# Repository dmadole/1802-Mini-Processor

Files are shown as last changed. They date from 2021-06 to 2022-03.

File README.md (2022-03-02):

# 1802-Mini-Processor
This is the 1802 processor card for the [1802/Mini](https://github.com/dmadole/1802-Mini) system. It supports the following features:

* CDP1802, CDP1804 (A only), CDP1805, or CDP1806 processors
* 64K of memory in two 32K RAM, EPROM, or EEPROM devices
* Supports 62C64, 62C256, 27C64, 27C256, 28C64, 28C256
* Can temporarily map a ROM at $8000 to $0000 at reset
* Eight  indicator LEDS with selectable polarity for each
* TTL level port with Q and selectable EF pin for soft serial
* Transmit and receive polarity selectable on serial port
* Designed for 4 Mhz but can run 8Mhz with suitable processor
* Stable power-on reset circuit is jumper-selectable
* Convenient mini-USB connector for 5 volt power input
* Form factor allows stacking or backplane by connector choice
* Can run totally standalone or expanded with additional cards
* Configurable to be able to run most "Classic Elf" software
* Highly annoted silkscreen documents most settings and pins

Gerber files for the PCBs and PDF schematics can be found in [Releases](https://github.com/dmadole/1802-Mini-Processor/releases).

BOMS and any applicable errata or other notes can be found in [notes](https://github.com/dmadole/1802-Mini-Processor/tree/main/notes).

For availability of kits and bare PCBs please see http://madole.net/1802/mini/kits

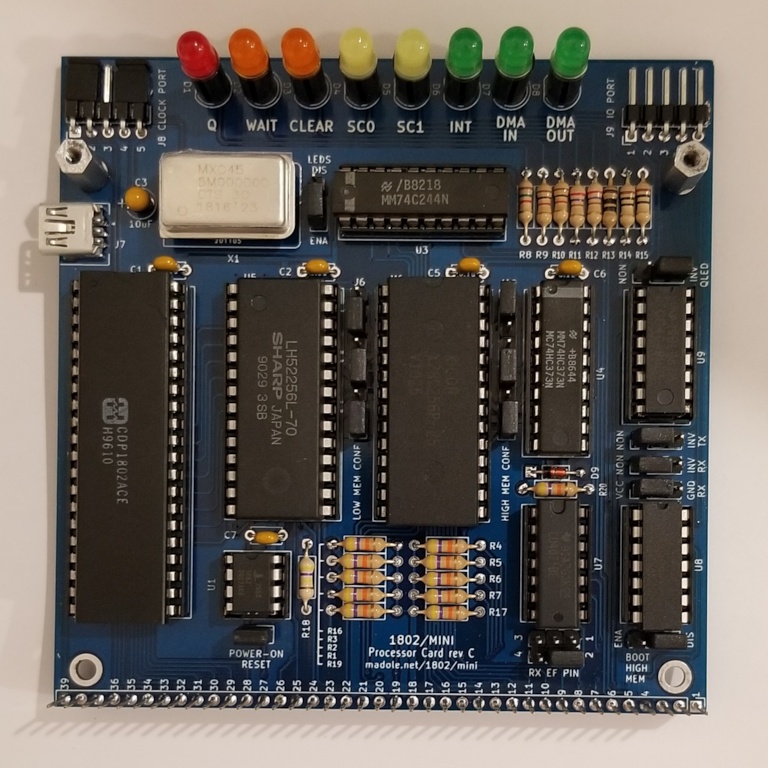
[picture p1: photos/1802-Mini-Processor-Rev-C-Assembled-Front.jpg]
1802/Mini Processor Front

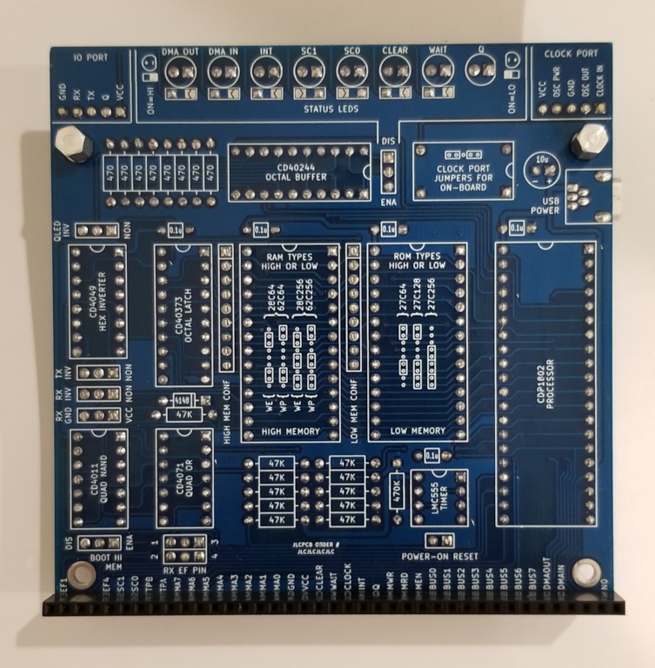
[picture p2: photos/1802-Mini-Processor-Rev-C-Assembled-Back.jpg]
1802/Mini Processor Back


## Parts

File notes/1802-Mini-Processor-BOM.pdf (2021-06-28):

Please refer to these notes as applicable for the parts list below:

*A

*B | Rev A and Rev B boards and schematics specified 47K ohms for all of R1-7 and R16-19. Recommended values are shown as below, use location reference for placement.
*C | The header pins for configuration jumpers are cut down from longer strips.
*D | The Samtec 39 pin connector, when ordering from Digikey, will always show zero stock because they are made-to-order. They will ship same or next day though.
*E | Virtually any of the many 555 timer clones can be subtituted, with CMOS parts preferred. The part numbers shown are not the only possible substitutes.

### PROCESSOR CARD

Qty | Description | Manufacturer Manufacturer # | Vendor | Vendor # | Price | Qty | Total

Integrated Circuits
1 | CDP1802 | U2 | Harris | CDP1802AEX | Rochester CDP1802AEX | 5.46 | 1.00 | 5.46
1 | 32K x 8 CMOS SRAM | U5 | Sharp | LM62256L-70 | Jameco | 82472 | 3.95 | 1.00 | 3.95
1 | 32K x 8 CMOS EEPROM | U6 | Atmel | 28C256-25 | Jameco | 74878 | 4.95 | 1.00 | 4.95
1 | CD40244 (or 74C244 or 74HC244) | U3 | TI | SN74HC244N | Digikey | 296-1582-5-ND | 0.61 | 1.00 | 0.61
1 | CD40373 (or 74C373 ot 74HC373) | U4 | TI | SN74HC373N | Digikey | 296-1591-5-ND | 0.66 | 1.00 | 0.66
1 | CD4049 | U9 | TI | CD4049UBE | Digikey | 296-2055-5-ND | 0.66 | 1.00 | 0.66
1 | CD4071 | U7 | TI | CD4071BE | Digikey | 296-2062-ND | 0.66 | 1.00 | 0.66
1 | CD4011 | U8 | TI | CD4011BE | Digikey | 296-2031-ND | 0.66 | 1.00 | 0.66
1 | LMC555 (or ICP7555) (*E) | U1 | Renesas | ICM7555IPAZ | Digikey | ICM7555IPAZ-ND | 0.87 | 1.00 | 0.87
1 | Oscillator module full size | X1 | Epson | MXO45-3C-4M000000 | Digikey | 110-MXO45-3C-4M000000-ND | 2.18 | 1.00 | 2.18

Discrete Components
1 | LED T1-3/4 Red (*A) | D1 | Valuepro | UT1871-81-M1-R | Jameco | 333973 | 0.12 | 1.00 | 0.12
2 | LED T1-3/4 Orange (*A) | D2-3 | Valuepro | LE3330 | Jameco | 107393 | 0.12 | 2.00 | 0.24
2 | LED T1-3/4 Yellow (*A) | D4-5 | Valuepro | LY3330 | Jameco | 34825 | 0.15 | 2.00 | 0.30
3 | LED T1-3/4 Green (*A) | D6-8 | Valuepro | LG3330 | Jameco | 34761 | 0.15 | 3.00 | 0.45
3 | Resistor 1/4 watt 10 (*A) | R13-15 | Stackpole | CF14JT10R0 | Digikey | CF14JT10R0CT-ND | 0.10 | 3.00 | 0.30
2 | Resistor 1/4 watt 270 (*A) | R11-12 | Stackpole | CF14JT270R | Digikey | CF14JT270RCT-ND | 0.10 | 2.00 | 0.20
2 | Resistor 1/4 watt 1K (*A) | R9,R10 | Stackpole | CF14JT1K00 | Digikey | CF14JT1K00CT-ND | 0.10 | 2.00 | 0.20
2 | Resistor 1/4 watt 1.5K (*A) | R8 | Stackpole | CF14JT1K50 | Digikey | CF14JT1K50CT-ND | 0.10 | 2.00 | 0.20
10 | Resistor 1/4 watt 4.7K (*B) | R1-7,16-17,19 | Stackpole | CF14JT4K70 | Digikey | CF14JT4K70CT-ND | 0.10 | 10.00 | 1.00
1 | Resistor 1/4 watt 47K (*B) | R20 | Stackpole | CF14JT47K0 | Digikey | CF14JT47K0CT-ND | 0.10 | 1.00 | 0.10
1 | Resistor 1/4 watt 470K | R18 | Stackpole | CF14JT470K | Digikey | CF14JT470KCT-ND | 0.10 | 1.00 | 0.10
1 | Diode 1N4148 | D9 | ON Semi | 1N4148 | Digikey | 1N4148FS-ND | 0.10 | 1.00 | 0.10
5 | Ceramic capacitor 0.1uF radial 0.2" | C1-2,5-7 | Valuepro | SR215C104KAA | Jameco | 544921 | 0.19 | 5.00 | 0.95
1 | Tantalum capacitor 10uF radial 0.1" | C3 | AVX | TAP106K010SCS | Digikey | 478-1838-ND * | 0.8 | 1.00 | 0.80

Interconnects
1 | Straight header 2 pins 0.1" (*C) | | Sullins | PREC040SAAN-RC | Digikey | S1012EC-40-ND | 0.51 | 0.05 | 0.03
8 | Straight header 3 pins 0.1" (*C) | | Sullins | PREC040SAAN-RC | Digikey | S1012EC-40-ND | 0.51 | 0.60 | 0.31
2 | Straight header 9 pins 0.1" (*C) | | Sullins | PREC040SAAN-RC | Digikey | S1012EC-40-ND | 0.51 | 0.45 | 0.23
2 | Right-angle header 5 pins 0.1" (*C) | | Sullins | PREC040SBAN-M71RC | Digikey | S1112EC-40-ND | 0.66 | 0.25 | 0.17
16 | Jumper shunts 0.1" | | Sullins | STC02SYAN | Digikey | S9000-ND | 0.10 | 16.00 | 1.60
1 | Socket 39 pin 0.1" long tail (*D) | | Samtec | SSQ-139-03-T-S | Digikey | SAM1206-39-ND | 4.52 | 1.00 | 4.52
1 | Mini-USB receptable AB | | Molex | 565790519 | Digikey | WM17121-ND | 2.54 | 1.00 | 2.54

Sockets
1 | DIP socket 40 pin 0.6" | | On Shore | ED40DT | Digikey | ED3048-5-ND | 0.48 | 1.00 | 0.48
2 | DIP socket 28 pin 0.6" | | On Shore | ED28DT | Digikey | ED3052-5-ND | 0.34 | 2.00 | 0.68
2 | DIP socket 20 pin 0.3" | | On Shore | ED20DT | Digikey | ED3054-5-ND | 0.26 | 2.00 | 0.52
1 | DIP socket 16 pin 0.3" | | On Shore | ED16DT | Digikey | ED3046-5-ND | 0.19 | 1.00 | 0.19
2 | DIP socket 14 pin 0.3" | | On Shore | ED14DT | Digikey | ED3045-5-ND | 0.19 | 2.00 | 0.38
1 | DIP socket 8 pin 0.3" | | On Shore | ED08DT | Digikey | ED3044-5-ND | 0.16 | 1.00 | 0.16
1 | DIP socket 4 pin in 14 pin frame 0.3" | | On Shore | ED14DT | Digikey | ED3045-5-ND | 0.19 | 1.00 | 0.19

Mechanical
8 | LED stand-off spacer | | VCC | STD_500_BLK | Jameco | 2231371 | 0.15 | 8.00 | 1.20
4 | 0.5 inch standoff spacer | | RAF | 4505-440-AL-7 | Jameco | 393474 | 0.49 | 4.00 | 1.96
1 | Circuit Board | | Madole | | JLCPCB | | 1.95 | 1.00 | 1.95
| | | | | | | Total | | 42.82

The LEDs and resistors shown are personal preference for color and with resistance values chosen to give equal brightness from all colors for these particular LEDs. Disregard the silkscreen value of 470 ohms when using these values and refer to reference number instead for location.

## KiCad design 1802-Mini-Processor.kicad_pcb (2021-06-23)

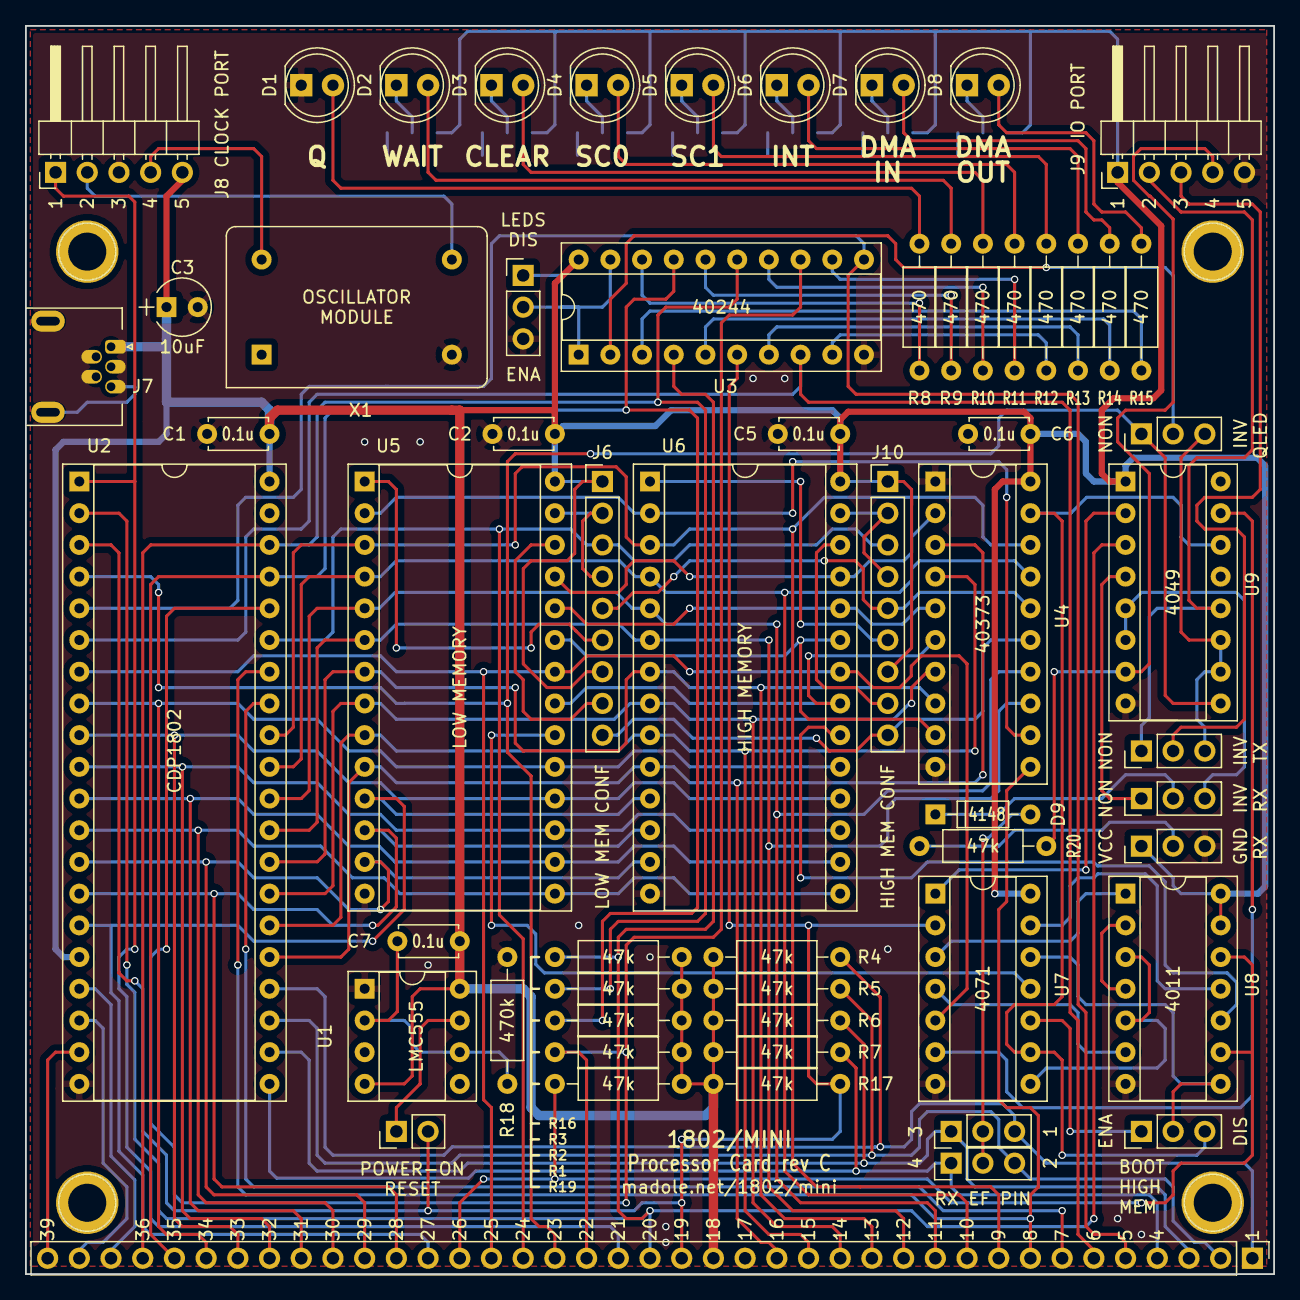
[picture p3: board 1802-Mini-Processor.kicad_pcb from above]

Board: 2 copper layers, 100.0 x 100.0 mm, 71 parts (0 on the bottom side), 102 nets.

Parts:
C1, C2, C5, C6, C7: 0.1u; C_Disc_D4.7mm_W2.5mm_P5.00mm
C3: 10uF; CP_Radial_Tantal_D4.5mm_P2.50mm
D1, D2, D3, D4, D5, D6, D7, D8: LED_Small; LED_D5.0mm
D9: 4148; D_DO-35_SOD27_P7.62mm_Horizontal
J1, J2, J3, J4: Mount; 1pin
J5: Expansion; Pin_Header_Straight_1x39_Pitch2.54mm
J6: SLOT_1_CONFIG; Pin_Header_Straight_1x09_Pitch2.54mm
J7: 56579-0519; USB_Mini-AB_Molex_56579_0519
J8: ClockPort; Pin_Header_Angled_1x05_Pitch2.54mm
J9: Q_Connector; Pin_Header_Angled_1x05_Pitch2.54mm
J10: SLOT_2_CONFIG; Pin_Header_Straight_1x09_Pitch2.54mm
JP1: POR; Pin_Header_Straight_1x02_Pitch2.54mm
JP3: WAIT; SolderJumper-3_P2.0mm_Open_TrianglePad1.0x1.5mm_NumberLabels
JP4: CLEAR; SolderJumper-3_P2.0mm_Open_TrianglePad1.0x1.5mm_NumberLabels
JP5: SC0; SolderJumper-3_P2.0mm_Open_TrianglePad1.0x1.5mm_NumberLabels
JP6: SC1; SolderJumper-3_P2.0mm_Open_TrianglePad1.0x1.5mm_NumberLabels
JP7: INT; SolderJumper-3_P2.0mm_Open_TrianglePad1.0x1.5mm_NumberLabels
JP8: TX_INV; Pin_Header_Straight_1x03_Pitch2.54mm
JP9, JP16: RX_SEL; Pin_Header_Straight_1x03_Pitch2.54mm
JP10: RX_INV; Pin_Header_Straight_1x03_Pitch2.54mm
JP11: RX_IDL; Pin_Header_Straight_1x03_Pitch2.54mm
JP12: BM_OE; Pin_Header_Straight_1x03_Pitch2.54mm
JP13: SLOT2_MIR; Pin_Header_Straight_1x03_Pitch2.54mm
JP14: DMAIN; SolderJumper-3_P2.0mm_Open_TrianglePad1.0x1.5mm_NumberLabels
JP15: DMAOUT; SolderJumper-3_P2.0mm_Open_TrianglePad1.0x1.5mm_NumberLabels
JP17: Q_LED; Pin_Header_Straight_1x03_Pitch2.54mm
R1, R2, R3, R4, R5, R6, R7, R16, R17, R19, R20: 47k; R_Axial_DIN0207_L6.3mm_D2.5mm_P10.16mm_Horizontal
R8, R9, R10, R11, R12, R13, R14, R15: 470; R_Axial_DIN0207_L6.3mm_D2.5mm_P10.16mm_Horizontal
R18: 470k; R_Axial_DIN0207_L6.3mm_D2.5mm_P10.16mm_Horizontal
U1: LMC555; DIP-8_W7.62mm_Socket
U2: CDP1802; DIP-40_W15.24mm_Socket
U3: 40244; DIP-20_W7.62mm_Socket
U4: 40373; DIP-20_W7.62mm_Socket
U5: LO_MEM; DIP-28_W15.24mm_Socket
U6: HI_MEM; DIP-28_W15.24mm_Socket
U7: 4071; DIP-14_W7.62mm_Socket
U8: 4011; DIP-14_W7.62mm_Socket
U9: 4049; DIP-16_W7.62mm_Socket
X1: CXO-DIP14; Oscillator_DIP-14

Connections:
/BUS0: J5.27, U2.15, U5.11, U6.11
/BUS1: J5.28, U2.14, U5.12, U6.12
/BUS2: J5.29, U2.13, U5.13, U6.13
/BUS3: J5.30, U2.12, U5.15, U6.15
/BUS4: J5.31, U2.11, U5.16, U6.16
/BUS5: J5.32, U2.10, U5.17, U6.17
/BUS6: J5.33, U2.9, U5.18, U6.18
/BUS7: J5.34, U2.8, U5.19, U6.19
/CLK_PWR: J8.4, X1.14
/MA0: J5.16, U2.25, U4.3, U5.10, U6.10
/MA1: J5.15, U2.26, U4.4, U5.9, U6.9
/MA2: J5.14, U2.27, U4.7, U5.8, U6.8
/MA3: J5.13, U2.28, U4.8, U5.7, U6.7
/MA4: J5.12, U2.29, U4.13, U5.6, U6.6
/MA5: J5.11, U2.30, U4.14, U5.5, U6.5
/MA6: J5.10, U2.31, U4.17, U5.4, U6.4
/MA7: J5.9, U2.32, U4.18, U5.3, U6.3
/MA8: U4.2, U5.25, U6.25
/MA9: U4.5, U5.24, U6.24
/MA10: U4.6, U5.21, U6.21
/MA11: U4.9, U5.23, U6.23
/MA12: U4.12, U5.2, U6.2
/MA13: J6.9, J10.9, U4.15
/MA14: J6.5, J10.5, U4.16
CLOCK: J5.21, J8.1, U2.1
DMA_IN: J5.36, R3.1, U2.38, U3.15
DMA_OUT: J5.35, R2.1, U2.37, U3.17
EF1: J5.1, JP9.3, R4.1, U2.24
EF2: J5.2, JP16.3, R5.1, U2.23
EF3: J5.3, JP9.1, R6.1, U2.22
EF4: J5.4, JP16.1, R7.1, U2.21
GND: C1.2, C2.2, C3.2, C5.2, C6.2, D1.1, J5.17, J7.5, J7.6, J8.3, J9.5, JP3.3, JP4.3, JP5.3, JP6.3, JP7.3, JP11.3, JP12.3, JP14.3, JP15.3, R18.1, U1.1, U2.20, U3.10, U4.1, U4.10, U5.14, U6.14, U7.7, U8.7, U9.8, X1.7
INTERRUPT: J5.22, R1.1, U2.36, U3.13
MA15: JP13.3, U4.19, U7.9, U9.14
MEN: J5.26, R19.1, U8.9, U8.12
MRD: J5.25, U2.7, U5.22, U6.22, U7.5
MWR: J5.24, J6.3, J10.3, U2.35
N0: J5.39, U2.19
N1: J5.38, U2.18
N2: J5.37, U2.17
unnamed: C7.2, R18.2, U1.2, U1.6
unnamed: D1.2, R8.2
unnamed: D2.1, JP3.2
unnamed: D2.2, R9.2
unnamed: D3.1, JP4.2
unnamed: D3.2, R10.2
unnamed: D4.1, JP5.2
unnamed: D4.2, R11.2
unnamed: D5.1, JP6.2
unnamed: D5.2, R12.2
unnamed: D6.1, JP7.2
unnamed: D6.2, R13.2
unnamed: D7.1, JP14.2
unnamed: D7.2, R14.2
unnamed: D8.1, JP15.2
unnamed: D8.2, R15.2
unnamed: D9.1, JP10.2
unnamed: D9.2, JP9.2, JP16.2
unnamed: J6.2, J6.4, U5.27
unnamed: J6.6, U5.1
unnamed: J6.8, U5.26
unnamed: J8.2, X1.8
unnamed: J9.2, JP8.1, U9.12
unnamed: J9.3, JP8.2
unnamed: J9.4, R20.2, U9.7
unnamed: J10.2, J10.4, U6.27
unnamed: J10.6, U6.1
unnamed: J10.8, U6.26
unnamed: JP1.1, U1.7
unnamed: JP10.1, U9.4
unnamed: JP10.3, U9.5, U9.6
unnamed: JP11.2, R20.1
unnamed: JP12.2, U3.1, U3.19
unnamed: JP13.1, U7.10
unnamed: JP13.2, U7.12, U8.8
unnamed: JP17.2, U3.2
unnamed: R8.1, U3.18
unnamed: R9.1, U3.16
unnamed: R10.1, U3.14
unnamed: R11.1, U3.12
unnamed: R12.1, U3.9
unnamed: R13.1, U3.7
unnamed: R14.1, U3.5
unnamed: R15.1, U3.3
unnamed: U7.1, U9.2
unnamed: U7.3, U8.1
unnamed: U7.4, U8.6
unnamed: U7.6, U9.15
unnamed: U7.8, U8.3, U8.5
unnamed: U7.13, U8.11
unnamed: U8.2, U8.4
Q: J5.23, JP17.1, U2.4, U9.9
SC0: J5.6, U2.6, U3.8
SC1: J5.5, U2.5, U3.11
SLOT1_CS: U5.20, U7.11
SLOT2_CS: U6.20, U8.10
TPA: J5.8, U2.34, U4.11
TPB: J5.7, U2.33
VCC: C1.1, C2.1, C3.1, C5.1, C6.1, C7.1, J5.18, J6.1, J6.7, J7.1, J8.5, J9.1, J10.1, J10.7, JP3.1, JP4.1, JP5.1, JP6.1, JP7.1, JP11.1, JP12.1, JP14.1, JP15.1, R1.2, R2.2, R3.2, R4.2, R5.2, R6.2, R7.2, R16.2, R17.2, R19.2, U1.4, U1.8, U2.16, U2.40, U3.20, U4.20, U5.28, U6.28, U7.14, U8.13, U8.14, U9.1
~CLEAR: J5.19, JP1.2, R17.1, U2.3, U3.6, U7.2
~Q: JP8.3, JP17.3, U9.10, U9.11
~WAIT: J5.20, R16.1, U2.2, U3.4, U9.3

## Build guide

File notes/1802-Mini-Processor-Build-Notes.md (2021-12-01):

# 1802/Mini Processor Assembly Notes

Follow usual assembly practices, which I will not document here. I recommend installing the lowest-height components first (resistors, diodes, right-angle connectors), then the next higher (sockets), and so on.

There are a lot of options on this board and it's important to make sure all of them have been selected correctly. Some options are selected with jumpers on the front of the board, and some by bridging solder pads on the back of the board. The board will not work as expected without nearly all options selected one way or the other.

Please see any [applicable errata](https://github.com/dmadole/1802-Mini-Processor/tree/main/notes) before assembling.

## LED Installation and Jumpering

The LEDs can be individually selected for polarity, that is, whether they light on a high or low signal. For all the LEDs except Q, this selection is made by a combination of the direction that the LED is installed in, and the bridging of a corresponding solder pad on the back, and the two must match. See the legends on either side of the LED area on the back silkscreen for proper alignment and bridging. The Q LED, however, is always installed the same way as shown on the back silscreen, and the selection of lighting on high or low is made by a jumper on the front of the board.

One way to look at it (for the LEDs other than Q) is to choose which side to solder bridge depending on when you want the LED to light, and then install the LED with the flat to the same side as you bridged. Solder-bridge the pads on (and point the flat of the LED to) the left (toward the IO Port) to light when low, and on the right (toward the Clock Port) to light when high.

I prefer installing the LEDs so they light on an "active" state which means light on high for SC0 and SC1, and light on low for the other signals. This will also minimize the number of LEDs lit during normal run state, and hence minimize the power consumption. If you are planning on using with a front panel card, I recommend installing the LEDs with half-inch standoffs, otherwise they can be mounted flush to the board.

Note that the optimal current-limiting resistor values will vary depending on what color and part number of LED is installed and the 470 ohm value printed on the silkscreen is just a typical average value. You may want to adjust the resistors to suit the particular LEDs that are used. The bill of materials suggests some specific LEDs and corresponding resistor values that I like for those particular LEDs. If you choose to use the same ones, use the component references on the bill of material for placement of those (1.5K for red, 1K for orange, 270 for yellow, and 10 for green) and disregard the generic silkscreen value.

## Clock Selection and Jumpering

The 1802/Mini is designed for a 4 Mhz clock based on the most pessimistic assumptions about component timing. Typical ICs will easily run at 6 Mhz or higher and with the right processor and other optimal parts the board will run at 8 Mhz or more. It may be desirable to socket the oscillator so it can be changed. An oscillator socket can be made from a typical  14 pin socket by pushing up the extra pins from below and removing them. It is important to put jumpers on the clock port connector on pins 1-2 and 4-5, the board will not work without these.

## Reset and Front Panel

If you don't care about the power-on reset capability, you can leave off the LMC555 timer and it's capacitor, resistor, and jumper. Using power-on reset and the front panel do not conflict, you can use power on reset with the front panel as long as the RUN switch if left set. The processor card will work without the front panel; you will definitely want to enable power-on reset in this case.

## Power Input Source

If you don't care about USB power input, you can leave off the USB connector and 10uF capacitor. In this case you can feed power into the clock port, IO port, or expansion connctor.

## Memory Mapping

The low memory socket is mapped at 0000 and the high at 8000. The "boot high memory" option causes the high socket to appear at both 0000 and 8000 after system reset until the first read of an address at 8000 or above. This can be used to bootstrap a system from ROM that normally has RAM at 0000 by putting a jump instruction to high address space in the start of the ROM. Many existing ROM images work with this either intentionally or unintentionally as they start with a long jump instruction.

## Serial Port Polarity

The normal RX and TX jumper settings for use with typical 5 volt level serial interfaces and most software is TX and RX non-inverted, and RX at VCC. You proably also want Q inverted so that it only lights when data is transmitted. These can need to be reversed, however, depending on how software is written. Use EF3 for RX for running membership card software or EF2 for running Pico/Elf software.

## Lead Trimming

I like to cut all the pins on the back of the board, even the IC sockets, so they are tight with the solder. This can help with clearance on stacked boards, especially with a metal can oscillator. I then also sand over the surface lightly with an emery board to even them a little and remove sharp edges. Of course if you take this latter step, you will need to clean the board well after and be careful since the dust is conductive and probably contains lead, depending on your materials.

## Jumper Settings

The following are the recommended jumper settings for use with Elf/OS. These assume 32K RAM in low memory from 0000-7FFF and 32K EEPROM in high memory from 8000-FFFF, use of EF2 for serial input, and startup from ROM. These give compatibility with software intended for the Pico/Elf and so is most convenient for use with software for Elf/OS.

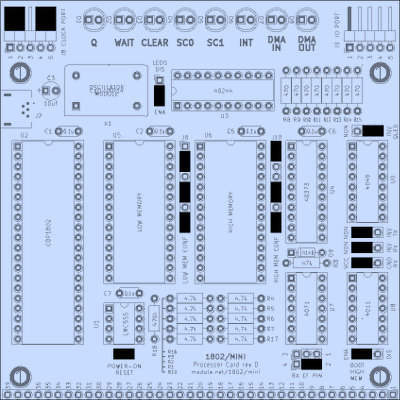
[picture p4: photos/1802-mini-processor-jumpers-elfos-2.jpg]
1802 Mini Processor Jumpers


If you are using an 1802/Mini specific build of Elf/OS BIOS that supports the 1854 UART with auto-detection of which port to use, you will want to set the RX GND jumper instead of RX VCC. This allows the BIOS to detect on EF2 when no cable is connected. Note that this does prevent EF2 from being used for anything else. This firmware is here:

https://github.com/dmadole/1802-Mini/tree/master/firmware

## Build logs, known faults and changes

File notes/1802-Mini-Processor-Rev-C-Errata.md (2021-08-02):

# 1802/Mini Processor Notes and Errata

I recommend changing the 47K resistors at R1-R7, R16, R17, and R19 on the 1802/Mini processor board to 4.7K to improve bus timing of open-drain signals at higher processor speeds. It takes approximately 600ms for the 47K pull-ups to bring a low signal back high after de-assertion and you will likely have difficulty running DMA at speeds over 2Mhz without this change as the signal will stretch into the next machine cycle.

It’s good enough to change just R2 and R3 for DMA but on new builds I recommend changing all 10 specified. As of Rev D of the board, the silkscreen has been updated to reflect this. There are no other changes in Rev D other than this cosmetic change.

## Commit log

2021-06-23 Initial upload
    [1802-Mini-Processor.kicad_pcb, 1802-Mini-Processor.sch]
2021-06-23 Add BOM
    [1802-Mini-Processor-BOM.xlsx]
2021-06-27 Added notes and reference numbers to BOM
    [1802-Mini-Processor-BOM.xlsx]
2021-06-28 Correct mfr part no of single row header
    [1802-Mini-Processor-BOM.xlsx]
2021-08-05 Update 1802-Mini-Processor-Build-Notes.md
    Added note about LED series resistor values
